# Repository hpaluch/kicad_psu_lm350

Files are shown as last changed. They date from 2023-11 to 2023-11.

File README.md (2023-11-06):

# 3A PSU with LM350

Project goal: Stabilized PSU with LM350 up to 3A and 33V output.

Created first prototype:
- file: [outputs/pcbway/lm350r0-pcbway.zip](outputs/pcbway/lm350r0-pcbway.zip)
- ordered on: https://www.pcbway.com/
- parameters:
  - 2 layers
  - 83.8 x 149.9 mm
  - thickness 1.6mm
  - Green mask

NOTE: Did not verified my prototype yet (planned around end of Dec 2023)

# Required software

KiCad 7, tested 7.0.8 under Windows 10

# Used parts

* LM350:
  - https://www.ti.com/lit/ds/symlink/lm350-n.pdf
  - https://www.hadex.cz/e643-lm350t-stabil12-33v3a-to220/
* 1N4007
  - https://www.tme.eu/Document/9313dc134fe45a55e51de6687beaf874/1n4001.pdf
  - https://www.hadex.cz/a045-1n4007-dioda-uni-1000v1a-do41/ 
* 1N5408
  - https://www.tme.eu/Document/04ec94aa0cc569e9a90a2bc04c8e62a4/1n5400_ser.pdf
  - https://www.hadex.cz/a041-1n5408-dioda-uni-1000v3a-do201/
* CAP polarized 2200uF/63V (2 pieces)
  - https://www.hadex.cz/i645-2200u63v-105-18x36x75mm-elektrolytkondenzator-radialni/
* CAP polarized 10uF/50V
  - https://www.hadex.cz/i870-10u50v-105-5x11x2mm-elektrolytkondenzator-radialni/
* CAP polarized 100uF/50V
  - https://www.hadex.cz/i874-100u50v-105-8x16x35mm-elektrolytkondenzator-radialni/
* Fuse holder PTF 60 for fuse 5x20mm (2pcs)
  - https://www.tme.eu/Document/a0fa896c2198407c3123a251856f56b8/PTF60.pdf
  - https://www.hadex.cz/k730f-pojistkovy-drzak-ptf-60-do-dps-pro-pojistku-5x20mm/
* Fuse 3A 5x20mm
  - https://www.hadex.cz/k817-pojistka-trubickova-5x20-f-315a/
* TODO: other parts

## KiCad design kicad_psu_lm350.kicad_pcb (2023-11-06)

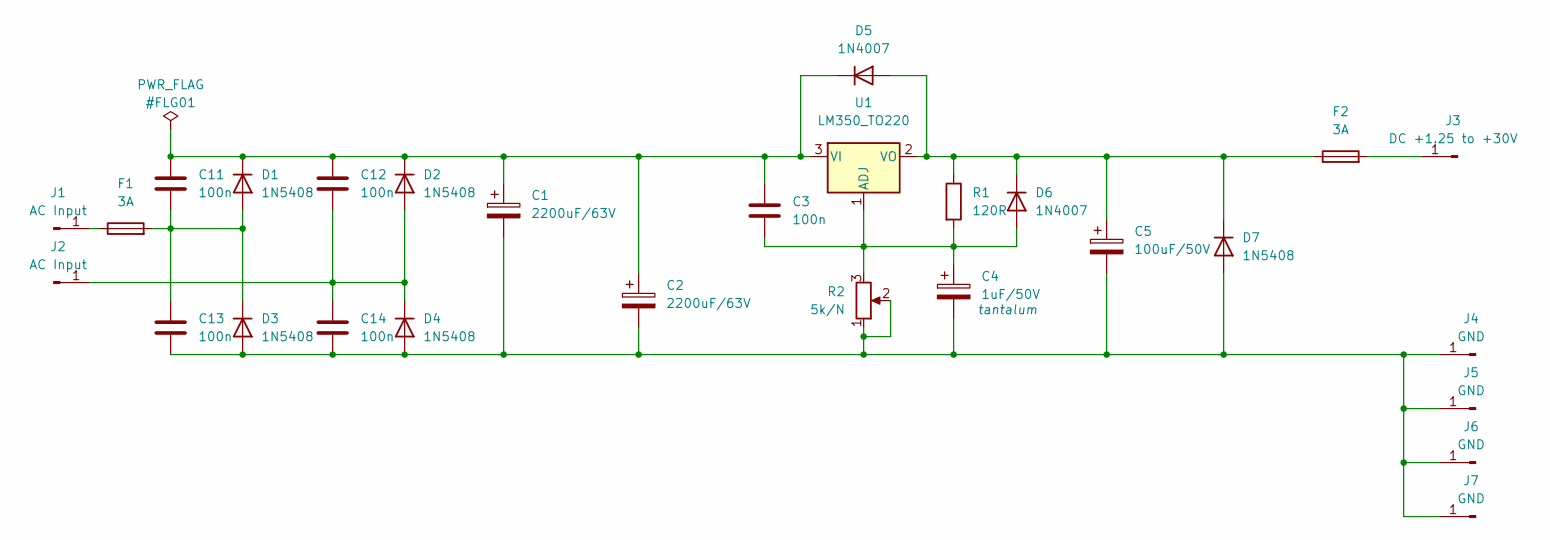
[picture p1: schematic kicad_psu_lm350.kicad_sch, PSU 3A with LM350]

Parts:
C1, C2: 2200uF/63V; CP_Radial_D18.0mm_P7.50mm
C3, C11, C12, C13, C14: 100n; C_Disc_D8.0mm_W5.0mm_P5.00mm
C4: 1uF/50V; CP_Radial_D5.0mm_P2.50mm
C5: 100uF/50V; CP_Radial_D8.0mm_P3.50mm
D1, D2, D3, D4, D7: 1N5408; D_DO-201AD_P15.24mm_Horizontal
D5, D6: 1N4007; D_DO-41_SOD81_P10.16mm_Horizontal
F1, F2: 3A; Fuseholder_Cylinder-5x20mm_Schurter_0031_8201_Horizontal_Op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
J1, J2: AC Input; PinSocket_1x01_P2.54mm_Vertical
J3: DC +1.25 to +30V; PinSocket_1x01_P2.54mm_Vertical
J4, J5, J6, J7: GND; PinSocket_1x01_P2.54mm_Vertical
R1: 120R; R_Axial_DIN0207_L6.3mm_D2.5mm_P10.16mm_Horizontal
R2: 5k/N; Potentiometer_Vishay_148-149_Single_Horizontal
U1: LM350_TO220; TO-220-3_Vertical

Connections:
unnamed: C1.1, C2.1, C3.1, C11.1, C12.1, D1.1 (K), D2.1 (K), D5.1 (K), U1.3 (VI)
unnamed: C1.2, C2.2, C4.2, C5.2, C13.2, C14.2, D3.2 (A), D4.2 (A), D7.2 (A), J4.1, J5.1, J6.1, J7.1, R2.1, R2.2
unnamed: C3.2, C4.1, D6.2 (A), R1.2, R2.3, U1.1 (ADJ)
unnamed: C5.1, D5.2 (A), D6.1 (K), D7.1 (K), F2.1, R1.1, U1.2 (VO)
unnamed: C11.2, C13.1, D1.2 (A), D3.1 (K), F1.2
unnamed: C12.2, C14.1, D2.2 (A), D4.1 (K), J2.1
unnamed: F1.1, J1.1
unnamed: F2.2, J3.1

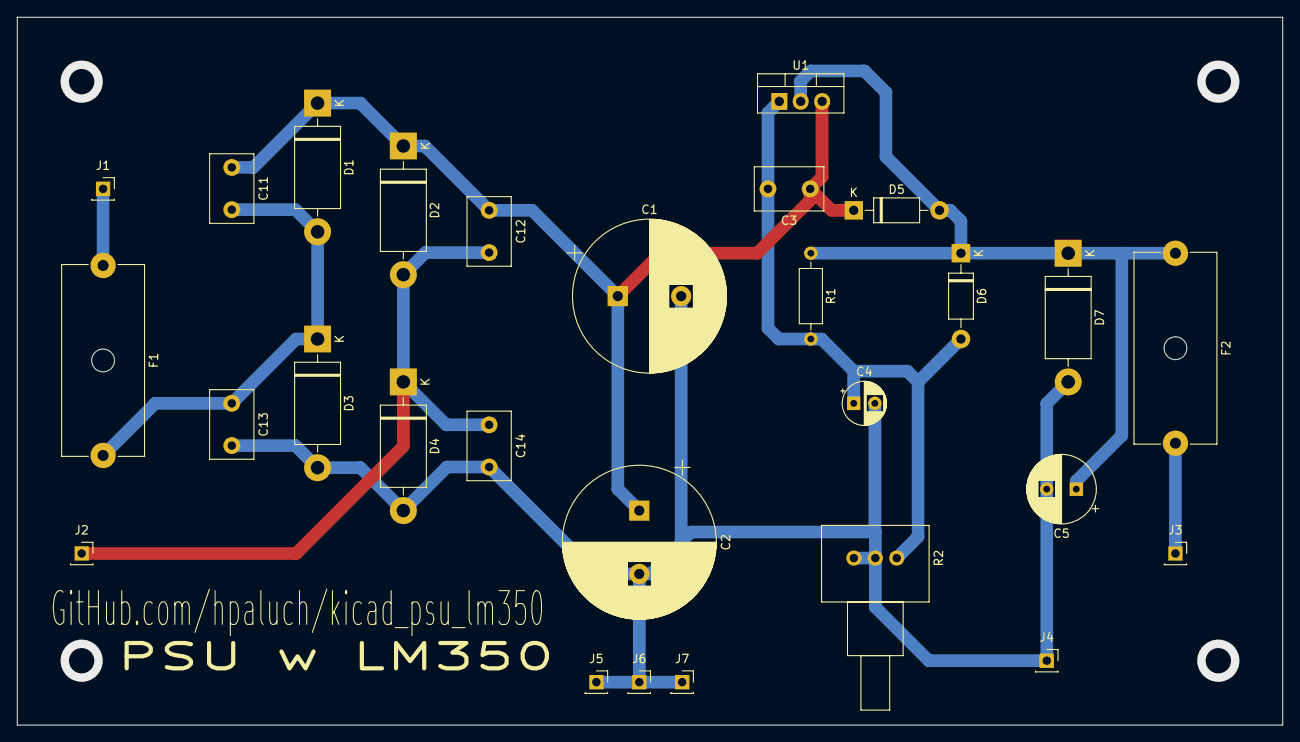
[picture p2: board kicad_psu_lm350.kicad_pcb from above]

Board: 2 copper layers, 149.9 x 83.8 mm, 28 parts (0 on the bottom side), 8 nets.

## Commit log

2022-12-29 Initial commit - just schematic
    [kicad_psu_lm350.kicad_pcb, kicad_psu_lm350.kicad_sch]
2022-12-29 Early footprint assignment
    [kicad_psu_lm350.kicad_sch]
2022-12-29 Early PCB placement
    [kicad_psu_lm350.kicad_pcb, kicad_psu_lm350.kicad_sch]
2022-12-30 Swapped pot pins, aligned schematic nets
    [kicad_psu_lm350.kicad_pcb, kicad_psu_lm350.kicad_sch]
2022-12-30 C4 should be tantalum to filter HF noise
    [kicad_psu_lm350.kicad_pcb, kicad_psu_lm350.kicad_sch]
2023-10-28 Upgraded to KiCad7, board outline, mounting holes
    [kicad_psu_lm350.kicad_pcb, kicad_psu_lm350.kicad_sch]
2023-10-28 Requires KiCad 7
2023-10-28 First routed version
    [kicad_psu_lm350.kicad_pcb]
2023-11-06 Created prototype - manufactured on pcbway.com
    [kicad_psu_lm350.kicad_pcb]
